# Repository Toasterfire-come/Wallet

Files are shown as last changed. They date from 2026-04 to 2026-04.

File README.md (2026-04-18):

# Metal Magsafe Wallet
A metal magsafe wallet designed to be rugged but comfortable. High tolerances and tight fits, designed to fit 2-3 cards comfortably and keep them inside. I built this project because I was tired of my plastic magsafe wallets breaking. I enjoyed their egonomic feel and slim form factor but did not like the fragility of each one. After 2-3 months every single one would break and crack down the side. I setout to build a metal wallet that could be easily taken appart and fixed. Oh no you sheered the screws off, well take them out and put new ones in problem solved. This project was designed on Fusion 360, and here was the process. I started with a base design of my wallet that I curently have (Speck Quicklock). I designed a base outline leaving ~2-4mm on each side and ~2mm on the top to allow of material. Then I designed the cutout, which had to have enough space for three cards and each card being 54x85.6x.7 mm and clearances because I did not want to use friction. Then I realized that there would be no way to construct a one part design without an internal lever to apply pressure so I cut ther design in half, added 2M screw holes, and built out the rest of my design. I researched many types of springs and spring mecanisms, I think the most viable actual spring would be a Torison bar, but I could not find one that would fit. I recognised that just a piece of metal ribbion when loaded also applies pressure like a spring and decided to use that. After calculating the nececary size, thickness, and length. I made further screw holes in the top to allow for this addition. I also added a magsafe cutout to allow for a 1mm magsafe addition for magsafe functionality. Then I chose proper products and had my part quoted.

Name,Purpose,Total Cost (USD)
M2 Self-Tapping Micro Screws- Screws to fasten the wallet together and to hold the spring. $5.98
Top Plate - The bottom machined enclosure.I built the cad file but posted to allow for viewing. - $38.28 
Bottom Plate - The bottom machined enclosure.I built the cad file but posted to allow for viewing - $37.72,
Gorilla 2 Part Epoxy - To secure magnets and screws. - $5.97
Magnet Sticker Circle - Allows magsafe functionality.-  $9.99
Stainless Steel Foil Roll- Acts as Spring that connects to top plate and applies constant pressure on cards. - $5.39

Links on CSV
Images Of Final Project.






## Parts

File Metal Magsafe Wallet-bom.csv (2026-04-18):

Name | Purpose | Quantity | Total Cost (USD) | Link | Distributor
M2 Self-Tapping Micro Screws | Screws to fasten the wallet together and to hold the spring. |  | 5.98 | https://www.amazon.com/gp/product/B0DGKF8DD9/ref=sw_img_1?smid=A13VMYFF52E90F&psc=1 | Amazon
Top Plate | The bottom machined enclosure.I built the cad file but posted to allow for viewing. | 1 | 38.28 | https://www.pcbway.com/project/shareproject/C_5C1W1025447A_Wallet_Bottom_e07cf743.html | PCBway
Bottom Plate | The bottom machined enclosure.I built the cad file but posted to allow for viewing |  | 37.72 | https://www.pcbway.com/project/shareproject/C_5C2W1025447A_Wallet_Top_4b32fc7b.html | PCBway
Gorilla 2 Part Epoxy | To secure magnets and screws. |  | 5.97 | https://www.amazon.com/Gorilla-Epoxy-Minute-ounce-Syringe/dp/B001Z3C3AG | Amazon
Magnet Sticker Circle | Allows magsafe functionality. | 1 | 9.99 | https://www.amazon.com/gp/product/B09FZ5Z7S4/ref=sw_img_1?smid=A10SCPSUX1IZI5&psc=1 | Amazon
Stainless Steel Foil Roll | Acts as Spring that connects to top plate and applies constant pressure on cards. |  | 5.39 | https://www.amazon.com/MECCANIXITY-Stainless-Flashing-Gloves-Electronic/dp/B0GK6T33DW | Amazon

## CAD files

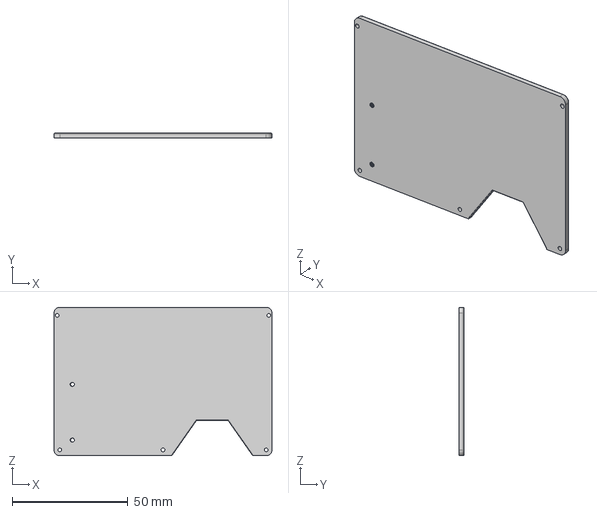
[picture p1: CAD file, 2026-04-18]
Wallet Top.step
94.0 x 2.00 x 64.0 mm

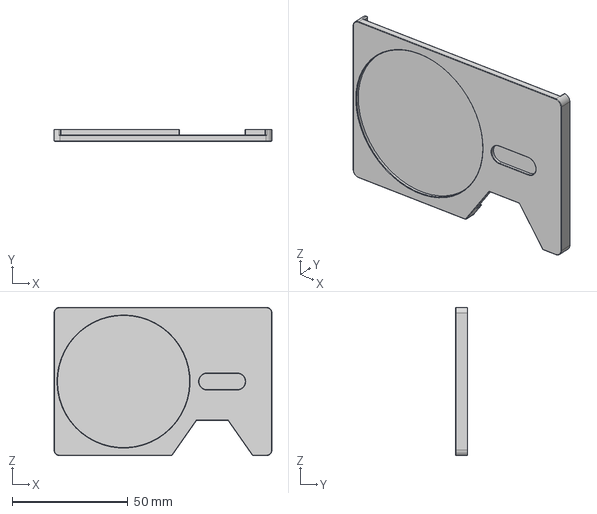
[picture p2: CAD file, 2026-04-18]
Wallet Bottom.step
94.0 x 5.00 x 64.0 mm

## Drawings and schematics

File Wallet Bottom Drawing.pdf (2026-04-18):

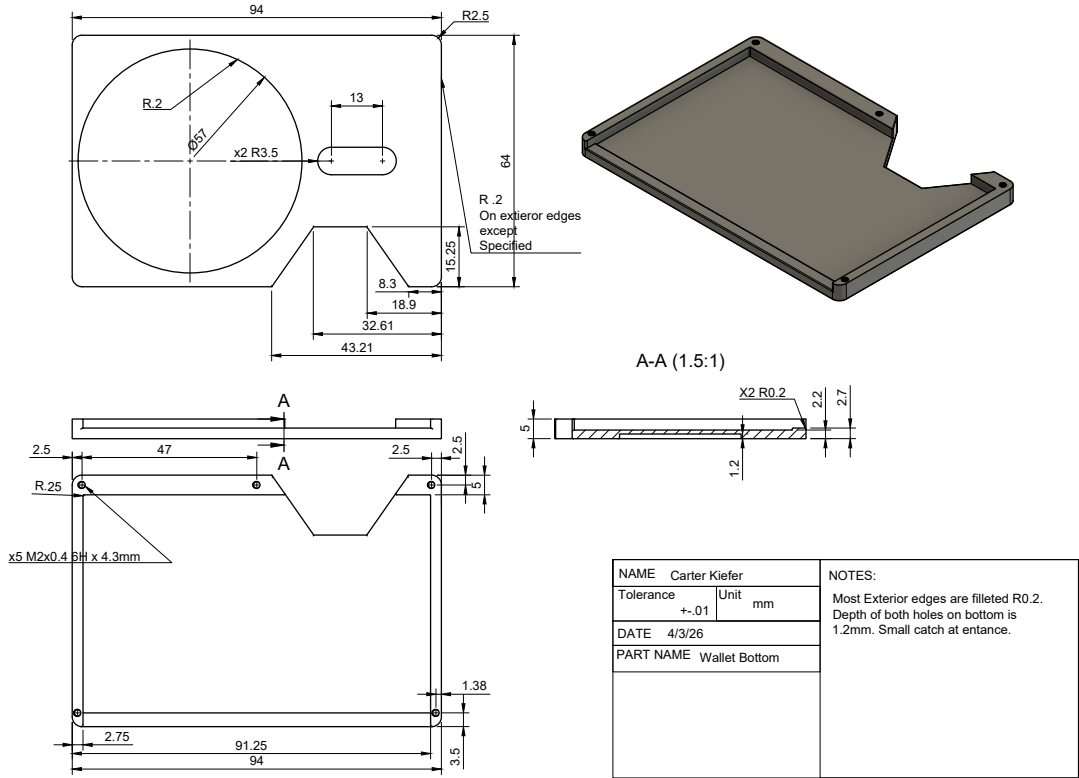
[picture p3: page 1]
R .2 On extieror edges; PART NAME; Wallet Bottom

NAME Carter Kiefer | NOTES: Most Exterior edges are filleted R0.2. Depth of both holes on bottom is 1.2mm. Small catch at entance.
Tolerance | Unit mm +-.01

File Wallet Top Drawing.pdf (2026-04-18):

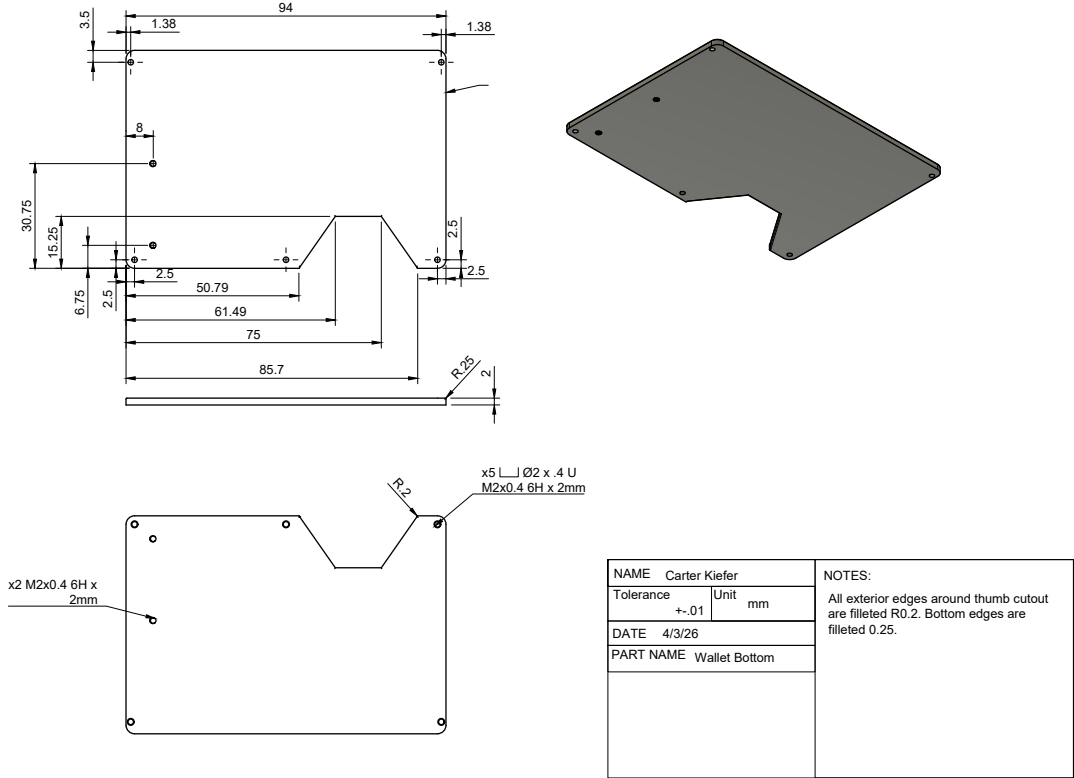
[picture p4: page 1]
All exterior edges around thumb cutout; PART NAME; Wallet Bottom

NAME Carter Kiefer | NOTES: are filleted R0.2. Bottom edges are filleted 0.25.
Tolerance | Unit mm +-.01
